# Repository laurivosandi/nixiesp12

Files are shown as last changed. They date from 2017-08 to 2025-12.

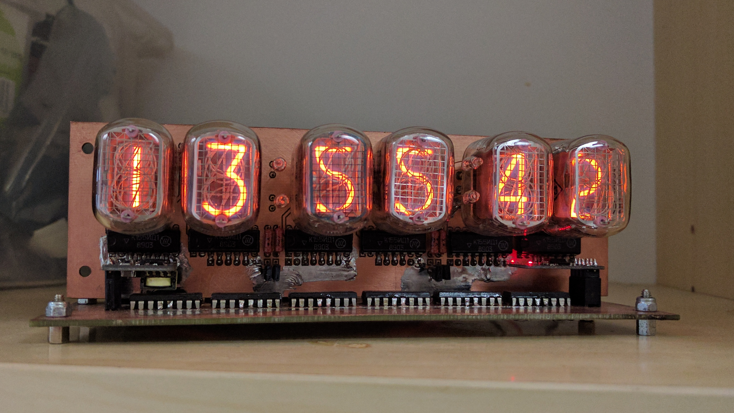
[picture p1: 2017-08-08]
photo.jpg

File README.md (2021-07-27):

# NixiESP12

## Intro

Yet another Nixie clock project!

Some highlights:

* K155ID1 driven IN-12A or IN-12B tubes for hour, minute, seconds. Use 36k resistors on these tubes.
* BS108 driven IN-6 or [similar 4*10mm neon bulbs](https://www.aliexpress.com/item/32344955038.html?spm=a2g0s.9042311.0.0.6ab14c4dCxpPZ0) for digit separation. Use 270k resistors on these bulbs.
* 74HC595 for serial to parallel conversion
* ESP8266 for time synchronization. Use 1k resistors for pull-up.
* LM1117-3.3V and LM1117-5V regulators for logic power supply
* No tube step up converter on-board, pin headers for connecting
  <a href="http://www.ebay.com/itm/DC-5V-12V-to-170V-DC-High-Voltage-NIXIE-Power-Supply-Module-PSU-NIXIE-TUBE-ERA-/322511957768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">third party power supply</a>
* KiCad design with 3D models from http://miniwatt.info

Some KiCad screenshots:



## Install

Install dependencies on an Ubuntu 18.04 box:

```bash
apt install -y python3-pip wget picocom make
pip3 install adafruit-ampy esptool
```

Boot ESP8266 with program pin held low and flash MicroPython:

```bash
cd firmware
make erase
make flash
```

Reboot ESP8266, open serial to to the controller and format filesystem:

```
import os
os.umount('/')
os.VfsLfs2.mkfs(bdev)
os.mount(bdev, '/')
```

Finish with by uploading scripts:

```bash
make upload
```

Power cycle the device and via WiFi connect to the device,
network name is MicroPython-XXXXXX and password is micropythoN.
Navigate to http://192.168.4.1 to start the configuration wizard.

## Configuring

If firmware is unable to connect to preconfigured wireless network
or it is started up for the first time wireless network
with password `micropythoN` is created.

Connect to that wireless network and open http://192.168.4.1
in web browser to configure the clock.

## Assembly tips

Some cheap 1117V regulators don't offer short circuit protection
and once blown pass through input voltage,
make sure you get ones with protection otherwise you can fry ESP8266
or serial-to-parallel chips.

Once the PCB is milled or etched make sure you clean the 180V rails thoroughly,
that voltage is high enough to cross gaps of 0.1mm.
Once that happens it burns a thick dark trace into the fiberglass of PCB and
it's pretty tricky to clean up.
The PCB is designed with 0.4mm clearance to be compliant with HV designs.
This clearance of course assumes that PCB traces are covered.
Either use solder mask or conformal coating.

Use the bench power supply to gradually power up the device,
at 9V set current limiter to 0.5A max.
5V linear regulator can be omitted and bypassed if 5V wall adapter is always used.
Otherwise 6V-12V wall adapters are suitable,
Thincan DBE60 9V wall adapters are pretty much perfect for the job.
Note that the higher the input voltage the more power is dissipated
as heat on the 3.3V and 5V voltage regulators, thus at 12V the device gets really hot.

## Debugging

* If you get nonsense reading during boot up sequence 0..9 likely the connection between serial-to-parallel chips and high voltage drivers
  is flaky. Either there are shorted pins or there is no connection at all. Check soldering joints and check for shorts between lines and line to ground.
* If single tube doesn't light up likely the gas has escaped the tube, find replacement tube.
* If single digit does not light up likely the tube socket pin is mangled or it is not properly soldered on the side where the PCB trace runs.

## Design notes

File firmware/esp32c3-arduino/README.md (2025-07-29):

# Arduino variant for ESP32C3

This firmware is designed to run on the [LilyGO T-01C3](https://lilygo.cc/products/t-01c3?srsltid=AfmBOopddAvO0gTIFNYZyTcoF1PxQjxZ0YAxuhoQviz9i5j4B0WOdg4l) board and serves as a drop-in replacement for the original ESP8266-based Nixie clock firmware.

**Compared to the ESP8266, the ESP32C3 provides much better clock accuracy and reliability, thanks to its advanced hardware and improved timekeeping features.**
If you received a Nixie clock from me, you are eligible for a free hardware upgrade - just contact me!

This firmware features a high refresh rate display with advanced dimming and blending effects, leveraging the ESP32's RMT (Remote Control) peripheral for precise timing and smooth transitions.

## Highlights

- **High Refresh Rate:** Achieves smooth digit transitions and flicker-free display using RMT hardware
- **Dimming & Blending:** Configurable dimming and blending for night mode and digit transitions
- **WiFiManager Configuration:** Easily configure all clock options via a web portal
- **Prometheus Metrics:** Exposes runtime and system metrics for monitoring

## Configuration Options via WiFiManager

- **NTP Time Server:** Set the network time server for clock synchronization
- **City:** Select your city for timezone presets
- **Timezone:** Manually specify the POSIX timezone string
- **Display Mode:** Choose between time, date, or alternating time/date display
- **Dimming Duty Cycle:** Adjust brightness for night mode
- **Dimming Start/End:** Set hours for automatic dimming
- **Blending Duration:** Control the duration of digit blending transitions
- **Hour Format:** Select 12-hour or 24-hour display

## Prometheus Metrics

The firmware exposes the following metrics for monitoring:

- `nixie_boot_timestamp_seconds`: Boot time of the device
- `nixie_last_ntp_sync_timestamp_seconds`: Last successful NTP synchronization
- `nixie_littlefs_total_bytes`: Total LittleFS storage size
- `nixie_littlefs_used_bytes`: Used LittleFS storage
- `nixie_uptime_seconds`: Device uptime
- `nixie_display_task_iterations_total`: Number of display task iterations
- `nixie_ntp_sync_count_total`: Number of NTP sync events
- `nixie_wifi_manager_process_count_total`: Number of WiFiManager process events

## Advanced Features

- **Automatic NTP Sync:** Periodically synchronizes time with the configured NTP server
- **Stale NTP Detection:** Blinks all digits and colons if NTP sync is stale
- **Critical Section Display Updates:** Uses FreeRTOS and portMUX for safe, high-speed display updates

## Getting Started

1. Flash the firmware to your ESP32-C3
2. Connect to the WiFiManager AP (SSID is based on device MAC)
3. Configure your clock settings via the web portal
4. Monitor metrics via Prometheus-compatible tools

---

For more details, see the source code and comments.

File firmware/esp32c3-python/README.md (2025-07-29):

# MicroPython variant for ESP32C3

This firmware is designed to run on ESP32-C3 boards using MicroPython. It drives a Nixie tube clock with high refresh rate, advanced dimming, and blending effects, leveraging the ESP32's RMT peripheral for precise timing

## Highlights

- **High Refresh Rate:** Smooth, flicker-free display using RMT hardware
- **Dimming & Blending:** Configurable night mode brightness and digit blending transitions
- **Configurable via `config.py`:** All major settings can be overridden by uploading a `config.py` file
- **NTP Synchronization:** Periodically syncs time with NTP servers
- **Timezone & DST Support:** Adjustable timezone and daylight saving settings

## Configuration Options

You can override any of these defaults by uploading a `config.py` file:

- `CONFIG_TIMEZONE`: Timezone offset from UTC (default: 2)
- `CONFIG_DAYLIGHT_SAVING_ENABLED`: Enable/disable DST (default: True)
- `CONFIG_NTP_SYNC_INTERVAL_HOURS`: NTP sync interval (default: 24)
- `CONFIG_DIMMING_ENABLED`: Enable night dimming (default: True)
- `CONFIG_DIMMING_BRIGHTNESS`: Night brightness (default: 0.4)
- `CONFIG_DIMMING_START`: Dimming start hour (default: 15)
- `CONFIG_DIMMING_END`: Dimming end hour (default: 6)
- `CONFIG_DIMMING_GAMMA`: Dimming gamma correction (default: 2.2)
- `CONFIG_BLENDING_ENABLED`: Enable digit blending (default: True)
- `CONFIG_BLENDING_DURATION`: Blending duration in ms (default: 150)
- `CONFIG_NETWORKS`: Dictionary of SSIDs and passwords for auto-connect

## Features

- **WiFi Auto-Connect:** Scans and connects to known networks
- **NTP Time Sync:** Sets system time via NTP after WiFi connection
- **Display Modes:** Time, date, and temperature rendering functions
- **RMT-Based Display:** Uses ESP32 RMT for precise display timing
- **Night Mode:** Automatic dimming based on configured hours
- **Blending:** Smooth digit transitions for improved aesthetics

## Usage

1. Flash MicroPython to your ESP32-C3 board
2. Upload `main.py` and (optionally) `config.py` to the device
3. Reboot the board. The clock will auto-connect to WiFi, sync time, and start displaying

## Notes

- The firmware is intended for advanced users familiar with MicroPython and ESP32 hardware
- For custom settings, create and upload a `config.py` file with your overrides
- RMT and SPI pin assignments are set for typical Nixie clock hardware; adjust as needed for your build

---

For more details, see the source code and

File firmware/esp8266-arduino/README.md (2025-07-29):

# Arduino variant for ESP8266

This firmware is designed for Nixie tube clocks using the ESP8266 microcontroller.

## Features

- WiFi configuration via captive portal (WiFiManager)
- NTP time synchronization
- Time and date display
- Timezone and NTP server configuration
- Clock drift mitigation using the ezTime library

## Note

The main issue with ESP8266-based clocks is clock drift. This firmware uses the ezTime library to reduce drift, but accuracy is still limited compared to ESP32-based

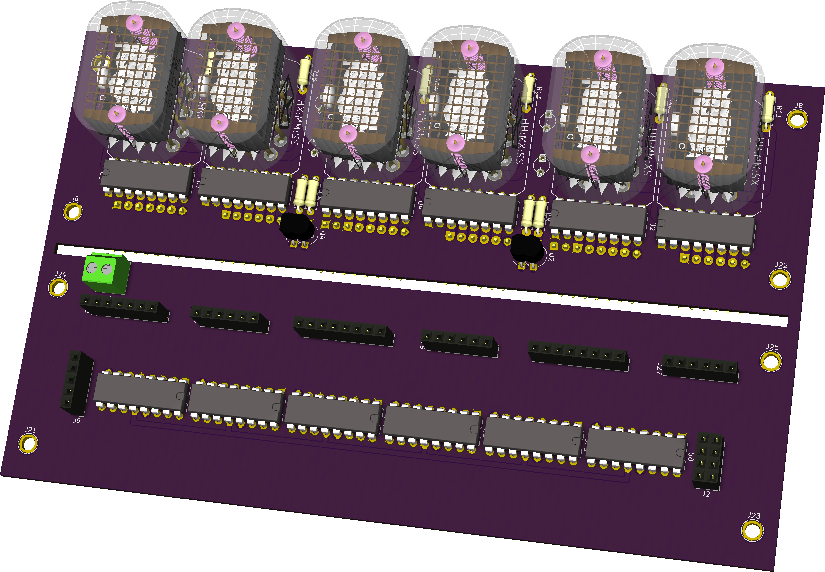
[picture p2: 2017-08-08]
nixiesp.png

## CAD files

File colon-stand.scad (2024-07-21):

H = 21;
Q = 1.2;
D = 1;
module j() {
    cylinder(h=100, d=D, $fn=20);
    translate([0,0,H-Q]) cylinder(5,0,5,$fn=20);
    cylinder(Q,Q,0,$fn=20);
}

difference() {
  hull() {
    translate([6.5, 0]) cylinder(h=H, d=4, $fn=50);
    translate([-6.5, 0]) cylinder(h=H, d=4, $fn=50);
  }
  translate([6.5, 0]) j();
  translate([-6.5, 0]) j();
  translate([3.5, 0]) j();
  translate([-3.5, 0]) j();

}

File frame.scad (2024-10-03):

PCB_THICKNESS = 1.7;
EDGE_LENGTH = 54;
WRAPAROUND = 2;

module thingie() {
  translate([1, 0, 0]) {
    difference() {
      cube([
        EDGE_LENGTH + 2 * WRAPAROUND,
        EDGE_LENGTH + 2 * WRAPAROUND*2 + PCB_THICKNESS,
        9]);
      translate([EDGE_LENGTH+17+5+3, EDGE_LENGTH+5+5]) {
        cylinder(10, EDGE_LENGTH+5, EDGE_LENGTH+5, $fn=500);
      };

      translate([-141,73]) {
        cylinder(10, 155, 155, $fn=500);
      };


      translate([WRAPAROUND, WRAPAROUND*3,1])  {
        translate([14, PCB_THICKNESS,0])  {
          cube([PCB_THICKNESS,EDGE_LENGTH,20]);
        }
        cube([EDGE_LENGTH,PCB_THICKNESS,20]);
      }
    }
  }
}

thingie();
mirror([1,0,0]) {
  thingie();
}

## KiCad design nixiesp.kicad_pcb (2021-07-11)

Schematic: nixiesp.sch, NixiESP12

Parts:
C1, C3: C; C_Disc_D4.3mm_W1.9mm_P5.00mm
C2, C4: CP; CP_Radial_D8.0mm_P3.50mm
J1: Power 9-15V; TerminalBlock_Pheonix_PT-3.5mm_2pol
J2: ESP8266; Socket_Strip_Straight_2x04_Pitch2.54mm
J3, J10, J12: CONN_01X06; Pin_Header_Angled_1x06_Pitch2.54mm
J4, J6, J13: CONN_01X07; Pin_Header_Angled_1x07_Pitch2.54mm
J5, J27, J29: CONN_01X06; Socket_Strip_Straight_1x06_Pitch2.54mm
J9: CONN_01X05; Socket_Strip_Straight_1x05_Pitch2.54mm
J11, J14, J31: CONN_01X07; Socket_Strip_Straight_1x07_Pitch2.54mm
J15, J16, J17, J18, J19, J20, J21, J23, J24, J25: CONN_01X01; 1pin
N1: HX:MM:SS; russian-nixies-IN-12
N2: XH:MM:SS; russian-nixies-IN-12
N3: HH:MX:SS; russian-nixies-IN-12
N4: HH:XM:SS; russian-nixies-IN-12
N5: HH:MM:SX; russian-nixies-IN-12
N6: HH:MM:XS; russian-nixies-IN-12
N7, N8, N9, N10: IN-6; russian-nixies-IN-6
Q1, Q2, Q3, Q4: BS107; TO-92_Inline_Wide
R1, R2: 2.2k; R_Axial_DIN0207_L6.3mm_D2.5mm_P7.62mm_Horizontal
R7, R8, R9, R10: 15k; R_Axial_DIN0207_L6.3mm_D2.5mm_P7.62mm_Horizontal
R11, R12, R13, R14, R15, R16: 10k; R_Axial_DIN0207_L6.3mm_D2.5mm_P7.62mm_Horizontal
U1, U5, U8, U11, U13, U14: 74HC595; DIP-16_W7.62mm
U2, U3, U4, U6, U7, U9: K155ID1; DIP-16_W7.62mm
U10: LM1117-5.0; SOT-223
U12: LM1117-3.3; SOT-223

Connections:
/data: J2.3, R2.2, U8.14 (SER)
/latch: J2.5, R1.1, U1.12 (RCLK), U5.12 (RCLK), U8.12 (RCLK), U11.12 (RCLK), U13.12 (RCLK), U14.12 (RCLK)
unnamed: J1.2, J9.1, U10.3 (VI), U12.3 (VI)
unnamed: J3.2, U2.7
unnamed: J3.3, U2.6
unnamed: J3.5, U2.4
unnamed: J3.6, U2.3
unnamed: J4.2, U3.7
unnamed: J4.3, U3.6
unnamed: J4.5, U3.4
unnamed: J4.6, U3.3
unnamed: J4.7, Q1.2 (G)
unnamed: J5.1, U1.2 (QC)
unnamed: J5.2, U1.3 (QD)
unnamed: J5.3, U1.4 (QE)
unnamed: J5.5, U1.5 (QF)
unnamed: J5.6, U1.6 (QG)
unnamed: J6.2, U6.7
unnamed: J6.3, U6.6
unnamed: J6.5, U6.4
unnamed: J6.6, U6.3
unnamed: J6.7, Q3.2 (G)
unnamed: J10.1, Q2.2 (G)
unnamed: J10.2, U4.7
unnamed: J10.3, U4.6
unnamed: J10.5, U4.4
unnamed: J10.6, U4.3
unnamed: J11.2, U11.3 (QD)
unnamed: J11.3, U11.4 (QE)
unnamed: J11.5, U11.5 (QF)
unnamed: J11.6, U11.6 (QG)
unnamed: J11.7, U1.1 (QB)
unnamed: J12.1, Q4.2 (G)
unnamed: J12.2, U7.7
unnamed: J12.3, U7.6
unnamed: J12.5, U7.4
unnamed: J12.6, U7.3
unnamed: J13.2, U9.7
unnamed: J13.3, U9.6
unnamed: J13.5, U9.4
unnamed: J13.6, U9.3
unnamed: J13.7, R7.1, R8.1, R9.1, R10.1, R11.1, R12.1, R13.1, R14.1, R15.1, R16.1
unnamed: J14.2, U13.3 (QD)
unnamed: J14.3, U13.4 (QE)
unnamed: J14.5, U13.5 (QF)
unnamed: J14.6, U13.6 (QG)
unnamed: J14.7, U5.1 (QB)
unnamed: J27.2, U8.3 (QD)
unnamed: J27.3, U8.4 (QE)
unnamed: J27.5, U8.5 (QF)
unnamed: J27.6, U8.6 (QG)
unnamed: J29.1, U5.2 (QC)
unnamed: J29.2, U5.3 (QD)
unnamed: J29.3, U5.4 (QE)
unnamed: J29.5, U5.5 (QF)
unnamed: J29.6, U5.6 (QG)
unnamed: J31.2, U14.3 (QD)
unnamed: J31.3, U14.4 (QE)
unnamed: J31.5, U14.5 (QF)
unnamed: J31.6, U14.6 (QG)
unnamed: J9.5, J31.7
unnamed: N1.0, U7.10
unnamed: N1.1, U7.14
unnamed: N1.2, U7.2
unnamed: N1.3, U7.15
unnamed: N1.4, U7.16
unnamed: N1.5, U7.1
unnamed: N1.6, U7.13
unnamed: N1.7, U7.11
unnamed: N1.8, U7.8
unnamed: N1.9, U7.9
unnamed: N1.A, R15.2
unnamed: N2.0, U9.10
unnamed: N2.1, U9.14
unnamed: N2.2, U9.2
unnamed: N2.3, U9.15
unnamed: N2.4, U9.16
unnamed: N2.5, U9.1
unnamed: N2.6, U9.13
unnamed: N2.7, U9.11
unnamed: N2.8, U9.8
unnamed: N2.9, U9.9
unnamed: N2.A, R16.2
unnamed: N3.0, U4.10
unnamed: N3.1, U4.14
unnamed: N3.2, U4.2
unnamed: N3.3, U4.15
unnamed: N3.4, U4.16
unnamed: N3.5, U4.1
unnamed: N3.6, U4.13
unnamed: N3.7, U4.11
unnamed: N3.8, U4.8
unnamed: N3.9, U4.9
unnamed: N3.A, R13.2
unnamed: N4.0, U6.10
unnamed: N4.1, U6.14
unnamed: N4.2, U6.2
unnamed: N4.3, U6.15
unnamed: N4.4, U6.16
unnamed: N4.5, U6.1
unnamed: N4.6, U6.13
unnamed: N4.7, U6.11
unnamed: N4.8, U6.8
unnamed: N4.9, U6.9
unnamed: N4.A, R14.2
unnamed: N5.0, U2.10
unnamed: N5.1, U2.14
unnamed: N5.2, U2.2
unnamed: N5.3, U2.15
unnamed: N5.4, U2.16
unnamed: N5.5, U2.1
unnamed: N5.6, U2.13
unnamed: N5.7, U2.11
unnamed: N5.8, U2.8
unnamed: N5.9, U2.9
unnamed: N5.A, R11.2
unnamed: N6.0, U3.10
unnamed: N6.1, U3.14
unnamed: N6.2, U3.2
unnamed: N6.3, U3.15
unnamed: N6.4, U3.16
unnamed: N6.5, U3.1
unnamed: N6.6, U3.13
unnamed: N6.7, U3.11
unnamed: N6.8, U3.8
unnamed: N6.9, U3.9
unnamed: N6.A, R12.2
unnamed: N7.A, R10.2
unnamed: N7.K, Q4.1 (D)
unnamed: N8.A, R7.2
unnamed: N8.K, Q1.1 (D)
unnamed: N9.A, R8.2
unnamed: N9.K, Q2.1 (D)
unnamed: N10.A, R9.2
unnamed: N10.K, Q3.1 (D)
unnamed: U1.9 (~QH), U14.14 (SER)
unnamed: U1.14 (SER), U11.9 (~QH)
unnamed: U5.9 (~QH), U11.14 (SER)
unnamed: U5.14 (SER), U13.9 (~QH)
unnamed: U8.9 (~QH), U13.14 (SER)

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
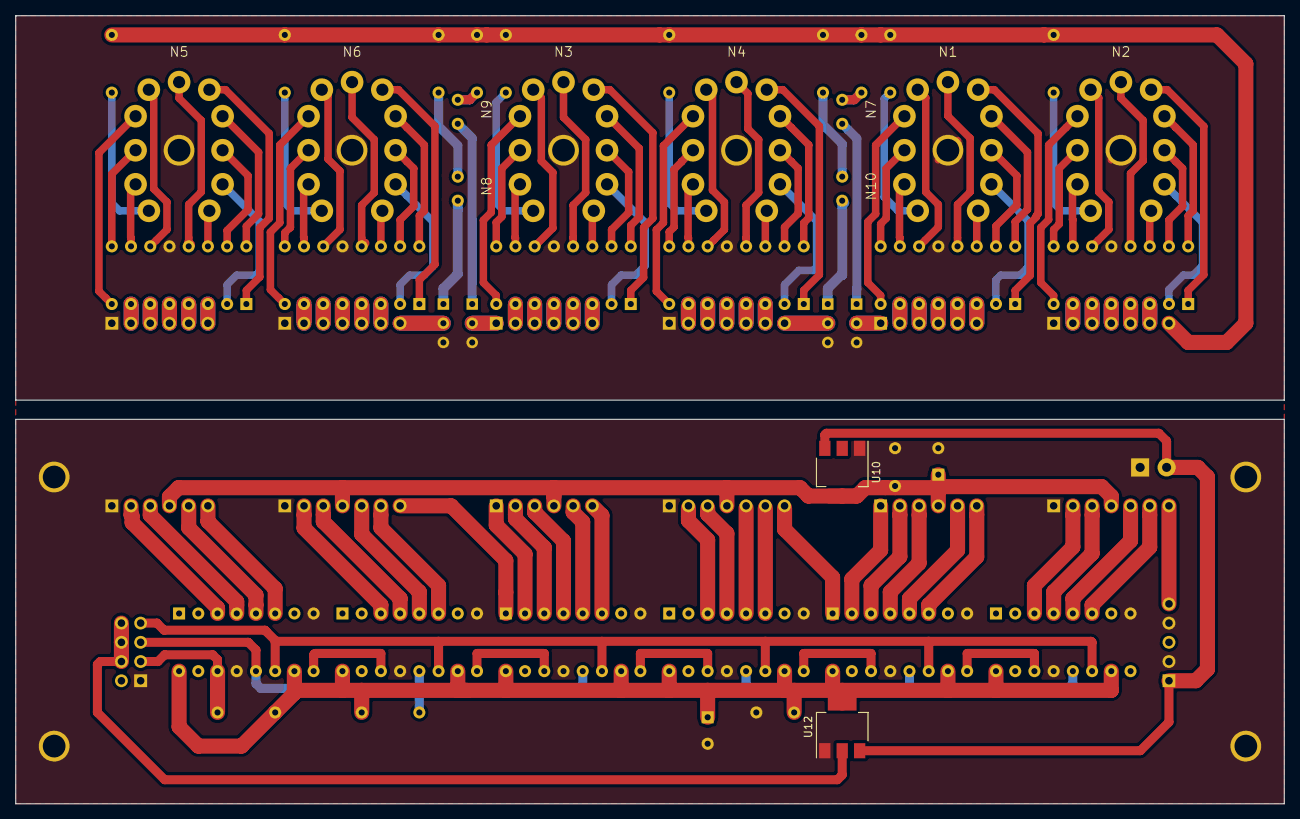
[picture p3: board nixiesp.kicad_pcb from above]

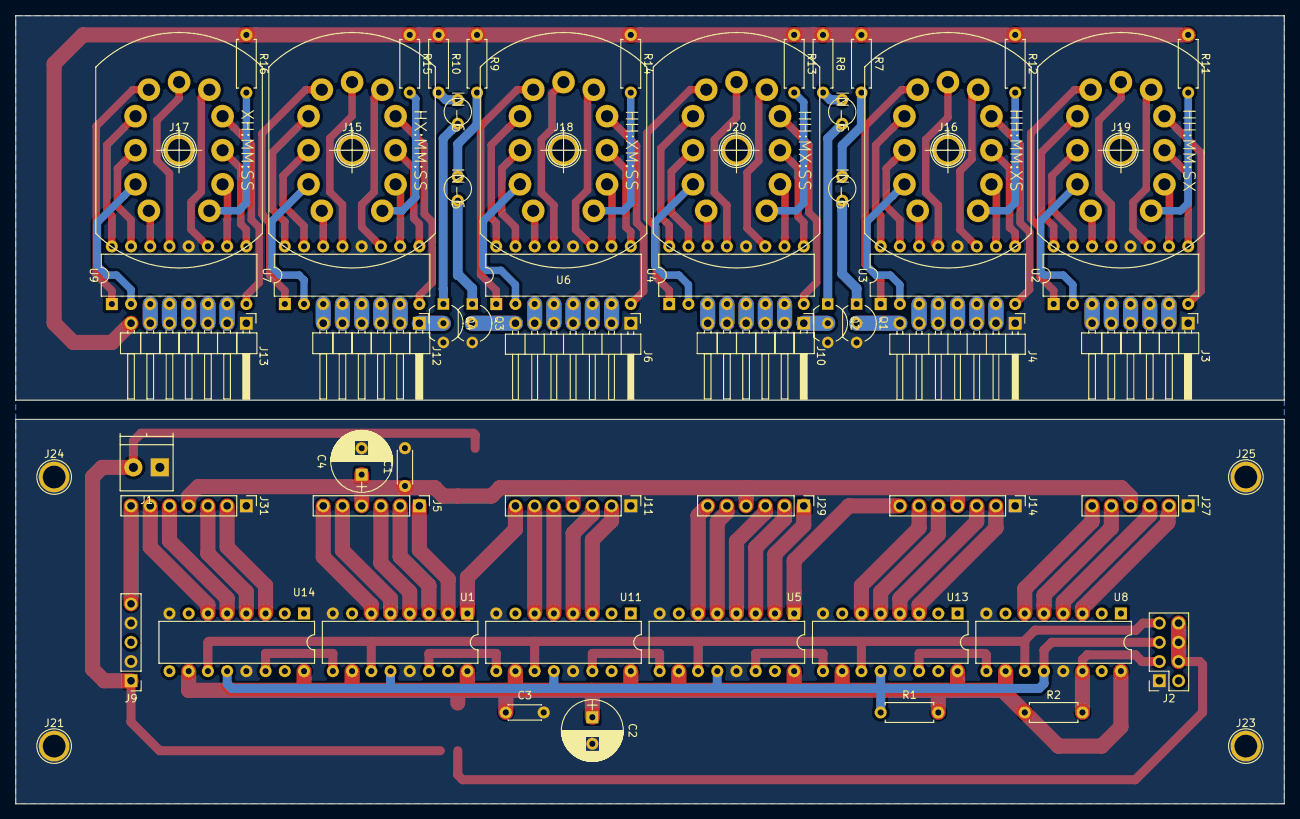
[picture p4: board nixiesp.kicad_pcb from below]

Board: 2 copper layers, 167.6 x 104.1 mm, 69 parts (67 on the bottom side), 143 nets.

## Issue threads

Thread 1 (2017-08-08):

Pull up resistors missing

laurivosandi, 2017-08-08:
Some of the ESP pins need pull up resistor to prevent booting into flashing mode

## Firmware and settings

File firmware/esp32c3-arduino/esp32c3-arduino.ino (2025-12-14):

#include <Arduino.h>
#include <WiFiManager.h>
#include <WiFi.h>
#include "esp_sntp.h"
#include <time.h>
#include <math.h>
#include <driver/rmt.h>
#include "cities.h"
#include <LittleFS.h>

// --- Configuration ---
#define CONFIG_CPU_FREQUENCY 80000000
#define CONFIG_RMT_DIVISOR 50
#define CONFIG_REFRESH_RATE 50
#define REFRESH_CYCLE CONFIG_CPU_FREQUENCY / CONFIG_RMT_DIVISOR / CONFIG_REFRESH_RATE - 100

static_assert(REFRESH_CYCLE > 0, "REFRESH_CYCLE must be > 0");
static_assert(REFRESH_CYCLE < 32768, "REFRESH_CYCLE must be < 32768");


// --- Pin Definitions ---
#define PIN_CLOCK 20
#define PIN_LATCH 9
#define PIN_DATA 2
#define PIN_UNUSED 11

// --- Colon and Symbol Definitions ---
#define COLON_LEFT_BOTTOM (1ULL << (17 + 16))
#define COLON_LEFT_TOP (1ULL << (18 + 16))
#define COLON_RIGHT_BOTTOM (1ULL << 17)
#define COLON_RIGHT_TOP (1ULL << 18)

#define COLON_LEFT_BOTH (COLON_LEFT_TOP | COLON_LEFT_BOTTOM)
#define COLON_RIGHT_BOTH (COLON_RIGHT_TOP | COLON_RIGHT_BOTTOM)
#define COLON_BOTTOM_BOTH (COLON_LEFT_BOTTOM | COLON_RIGHT_BOTTOM)
#define COLON_TOP_BOTH (COLON_LEFT_TOP | COLON_RIGHT_TOP)
#define COLON_ALL (COLON_LEFT_BOTH | COLON_RIGHT_BOTH)

#define IN15A_MICRO 0
#define IN15A_PERCENT 2
#define IN15A_PETA 3
#define IN15A_KILO 4
#define IN15A_MEGA 5
#define IN15A_MILLI 6
#define IN15A_PLUS 7
#define IN15A_MINUS 8
#define IN15A_PICO 9


#define NTP_SYNC_TIMEOUT_SECONDS 8*3600

int configDimmingDutyCycle = 0;
int configDimmingStart = 0;
int configDimmingEnd = 0;
int configHourFormat = 12;

int current_dimming_duty_cycle;
enum typeOperationMode {
  OPERATION_MODE_NORMAL,
  OPERATION_MODE_DIMMED,
} operationModeCurrent = OPERATION_MODE_NORMAL;

#define DISPLAY_MODE_TIME 1
#define DISPLAY_MODE_DATE 2
#define DISPLAY_MODE_DATETIME 3

int configDisplayModesEnabled = 1;
int displayModeCurrent = 1;

WiFiManager wm;

const char displayModesCombobox[] = R"(
<br/>
<label for="displayModeCombobox">Clock display format</label>
<select name="timeDisplay" id="displayModeCombobox" onchange="document.getElementById('displayMode').value = this.value">
  <option value="1">Time</option>
  <option value="2">Date</option>
  <option value="3">Time and Date</option>
</select>
<script>
  document.getElementById("displayModeCombobox").value = document.getElementById("displayMode").value;
  document.querySelector("[for='displayMode']").hidden = true;
  document.getElementById("displayMode").hidden = true;
</script>)";


WiFiManagerParameter paramNetworkTimeServer("networkTimeServer", "Network time server", "ee.pool.ntp.org", 63);
WiFiManagerParameter paramDisplayMode("displayMode", "Will be hidden", "1", 2);
WiFiManagerParameter paramDisplayModeCombobox(displayModesCombobox);
WiFiManagerParameter paramCity(cities);
WiFiManagerParameter paramTimezone("timezone", "Timezone encoding", "EET-2EEST,M3.5.0/3,M10.5.0/4", 30);
#define CONFIG_TIMEZONE "EET-2EEST,M3.5.0/3,M10.5.0/4" // Estonia, adjust as needed

const char dimmerSliderSnippet[] = R"(
<br/><label for='dimming_duty_cycle_slider'>Night time dimming duty cycle (%)</label>
<input type="range" min="500" max="32767" value="1000" class="slider" id="dimming_duty_cycle_slider" onchange="document.getElementById('dimming_duty_cycle').value = this.value">
<script>
document.getElementById('dimming_duty_cycle').hidden = true;
</script>
)";
WiFiManagerParameter paramDimmingDutyCycle("dimming_duty_cycle", "", "1000", 6);
WiFiManagerParameter paramDimmingDutyCycleSlider(dimmerSliderSnippet);

time_t bootTimestamp = 0;
time_t lastNtpSyncTimestamp = 0;


// Dimmer settings
volatile long displayInterruptCount = 0;

const char blendingSliderSnippet[] = R"(
<br/><label for='blending_duration_slider'>Blending duration (0 .. 400ms)</label>
<input type='range' min='0' max='400' value='200' class='slider' id='blending_duration_slider' onchange="document.getElementById('blending_duration').value = this.value">
<script>
document.getElementById('blending_duration').hidden = true;
</script>
)";
WiFiManagerParameter paramBlendingDuration("blending_duration", "", "200", 4);
WiFiManagerParameter paramBlendingDurationSlider(blendingSliderSnippet);


const char dimmingStartCombobox[] = R"(
<br/>
<label for='dimming_start_hour'>Night time dimming start time</label>
<select name='dimming_start' id='dimming_start_hour' onchange="document.getElementById('dimming_start').value = this.value">
  <option value='13'>13:00</option>
  <option value='14'>14:00</option>
  <option value='15'>15:00</option>
  <option value='16'>16:00</option>
  <option value='17'>17:00</option>
  <option value='18'>18:00</option>
  <option value='19'>19:00</option>
  <option value='20'>20:00</option>
  <option value='21'>21:00</option>
  <option value='22'>22:00</option>
  <option value='23'>23:00</option>
</select>
<script>
document.getElementById('dimming_start_hour').value = "22";
document.getElementById('dimming_start').hidden = true;
</script>
)";

const char dimmingEndCombobox[] = R"(
<br/>
<label for='dimming_end_hour'>Night time dimming end time</label>
<select name='dimming_end' id='dimming_end_hour' onchange="document.getElementById('dimming_end').value = this.value">
  <option value='4'>4:00</option>
  <option value='5'>5:00</option>
  <option value='6'>6:00</option>
  <option value='7'>7:00</option>
  <option value='8'>8:00</option>
  <option value='9'>9:00</option>
  <option value='10'>10:00</option>
  <option value='11'>11:00</option>
  <option value='12'>12:00</option>
</select>
<script>
document.getElementById('dimming_end_hour').value = "6";
document.getElementById('dimming_end').hidden = true;
</script>
)";

const char hourFormatCombobox[] = R"(
<br/>
<label for="hourFormatCombobox">Hour format</label>
<select name="hour_format" id="hourFormatCombobox" onchange="document.getElementById('hour_format').value = this.value">
  <option value="24">24-hour</option>
  <option value="12">12-hour</option>
</select>
<script>
  document.getElementById("hourFormatCombobox").value = "12";
  document.getElementById("hour_format").hidden = true;
</script>
)";

WiFiManagerParameter paramHourFormat("hour_format", "", "12", 3);
WiFiManagerParameter paramHourFormatCombobox(hourFormatCombobox);
WiFiManagerParameter paramDimmingStart("dimming_start", "", "22", 3);
WiFiManagerParameter paramDimmingStartCombobox(dimmingStartCombobox);
WiFiManagerParameter paramDimmingEnd("dimming_end", "", "6", 3);
WiFiManagerParameter paramDimmingEndCombobox(dimmingEndCombobox);

// --- NTP Sync Counter ---
volatile unsigned long displayTaskIterationsCount = 0;
volatile unsigned long configBlendingDuration = 0;
volatile unsigned long ntpSyncCount = 0;
volatile unsigned long wifiManagerProcessCount = 0;

void IRAM_ATTR timeavailable(struct timeval *t) {
    ntpSyncCount++;
    if (bootTimestamp == 0 && t) {
        bootTimestamp = t->tv_sec;
    }
    if (t) {
        lastNtpSyncTimestamp = t->tv_sec;
    }
}

#define RMT_TX_GPIO 9


// --- State ---
uint64_t STATE_PREVIOUS = 0x787878787878ULL;
int STATE_REFRESH_MODE = 0;

// --- Helper Functions ---
void spi_write_bytes(const uint8_t* data, size_t len) {
    for (size_t i = 0; i < len; i++) {
        uint8_t b = data[i];
        for (int bit = 7; bit >= 0; bit--) {
            digitalWrite(PIN_CLOCK, LOW);
            digitalWrite(PIN_DATA, (b >> bit) & 1);
            digitalWrite(PIN_CLOCK, HIGH);
        }
    }
}

int clamp(int v, int lower = -99, int upper = 99) {
    if (v > upper) return upper;
    if (v < lower) return lower;
    return v;
}

uint64_t render_digit(int j, int position = 0) {
    static const int table[11] = {11, 9, 12, 8, 0, 4, 1, 3, 2, 10, 15};
    if (j < -1 || j > 9) j = 10;
    if (j == -1) j = 10;
    return ((uint64_t)table[j] << 3) << (position * 8);
}

uint64_t render_digits(int d5, int d4, int d3, int d2, int d1, int d0) {
    uint64_t z = 0;
    int vals[6] = {d0, d1, d2, d3, d4, d5};
    for (int position = 0; position < 6; position++) {
        z |= render_digit(vals[position], position);
    }
    return z;
}

uint64_t render_time(bool colons = true) {
    struct tm timeinfo;
    time_t now = time(nullptr);
    localtime_r(&now, &timeinfo);
    int h = timeinfo.tm_hour % configHourFormat;
    if (configHourFormat == 12 && h == 0) {
        h = 12; // TODO: Parameter to configure 12-hour format
    }
    int m = timeinfo.tm_min;
    int s = timeinfo.tm_sec;
    return render_digits(h / 10, h % 10, m / 10, m % 10, s / 10, s % 10) | (colons ? COLON_ALL : 0);
}

uint64_t render_date(bool colons = true) {
    struct tm timeinfo;
    time_t now = time(nullptr);
    localtime_r(&now, &timeinfo);
    int y = timeinfo.tm_year % 100;
    int m = timeinfo.tm_mon + 1;
    int d = timeinfo.tm_mday;
    return render_digits(y / 10, y % 10, m / 10, m % 10, d / 10, d % 10) | (colons ? COLON_BOTTOM_BOTH : 0);
}

uint64_t render_temperature(int t) {
    int val = abs(clamp(t));
    return render_digits(-1, t < 0 ? IN15A_MINUS : -1, val / 10, val % 10, -1, -1) | COLON_RIGHT_TOP;
}

void rmt_pulse(uint32_t duration) {
    rmt_data_t items[3];
    items[0].level0 = 1; items[0].duration0 = 1; // latch immediately
    items[0].level1 = 0; items[0].duration1 = duration;
    items[1].level0 = 1; items[1].duration0 = 1;
    items[1].level1 = 0; items[1].duration1 = 1;
    rmtWriteAsync(RMT_TX_GPIO, items, duration == 0 ? 1 : 2);
}

void display_static(uint64_t value) {
    uint8_t bytes[6];
    for (int i = 0; i < 6; i++) bytes[i] = (value >> (8 * (5 - i))) & 0xFF;
    spi_write_bytes(bytes, 6);
    rmt_data_t items[1];
    items[0].level0 = 1; items[0].duration0 = 1;
    items[0].level1 = 0; items[0].duration1 = 1;
    rmtWrite(RMT_TX_GPIO, items, 1, RMT_WAIT_FOR_EVER);
}

void display_dimmed(uint64_t value, int duty) {
    uint8_t bytes[6];
    for (int i = 0; i < 6; i++) bytes[i] = (value >> (8 * (5 - i))) & 0xFF;
    if (duty >= 32767) {
        display_static(value);
    } else {
        spi_write_bytes(bytes, 6);
        rmt_pulse(duty);
        uint8_t blank[6] = {0x78, 0x78, 0x78, 0x78, 0x78, 0x78};
        spi_write_bytes(blank, 6);
    }
}

void display_blended(uint64_t value, uint64_t prev, float progression) {
    int duty = 32767 * progression;
    if (duty < 500) { duty = 500; }
    uint8_t bytes[6], prev_bytes[6];
    for (int i = 0; i < 6; i++) {
        bytes[i] = (value >> (8 * (5 - i))) & 0xFF;
        prev_bytes[i] = (prev >> (8 * (5 - i))) & 0xFF;
    }
    if (progression >= 1.0) {
        display_static(value);
    } else {
        spi_write_bytes(bytes, 6);
        rmt_pulse(duty);
        spi_write_bytes(prev_bytes, 6);
    }
}

bool isNtpStale() {
    time_t now = time(nullptr);
    return (lastNtpSyncTimestamp == 0) || (now - lastNtpSyncTimestamp > NTP_SYNC_TIMEOUT_SECONDS);
}

void handleMetrics(){
    String buf = "";


    buf += "nixie_sketch_size_bytes ";
    buf += ESP.getSketchSize();
    buf += "\n";

    buf += "nixie_flash_space_bytes ";
    buf += ESP.getFlashChipSize();
    buf += "\n";

    buf += "nixie_free_heap_bytes ";
    buf += ESP.getFreeHeap();
    buf += "\n";

    buf += "nixie_min_free_heap_bytes ";
    buf += ESP.getMinFreeHeap();
    buf += "\n";

    buf += "nixie_cpu_frequency_mhz ";
    buf += getCpuFrequencyMhz();
    buf += "\n";

    buf += "nixie_task_count ";
    buf += uxTaskGetNumberOfTasks();
    buf += "\n";

    buf += "nixie_wifi_rssi_dbm ";
    buf += WiFi.RSSI();
    buf += "\n";

    buf += "nixie_wifi_channel ";
    buf += WiFi.channel();
    buf += "\n";

    int wifiStatus = WiFi.status();
    const char* wifiStatusStr = "UNKNOWN";
    switch (wifiStatus) {
        case WL_IDLE_STATUS: wifiStatusStr = "IDLE"; break;
        case WL_NO_SSID_AVAIL: wifiStatusStr = "NO_SSID_AVAIL"; break;
        case WL_SCAN_COMPLETED: wifiStatusStr = "SCAN_COMPLETED"; break;
        case WL_CONNECTED: wifiStatusStr = "CONNECTED"; break;
        case WL_CONNECT_FAILED: wifiStatusStr = "CONNECT_FAILED"; break;
        case WL_CONNECTION_LOST: wifiStatusStr = "CONNECTION_LOST"; break;
        case WL_DISCONNECTED: wifiStatusStr = "DISCONNECTED"; break;
    }
    buf += "nixie_wifi_status_info{status=\"";
    buf += wifiStatusStr;
    buf += "\"} ";
    buf += wifiStatus;
    buf += "\n";

    buf += "nixie_wifi_info{ssid=\"";
    buf += WiFi.SSID();
    buf += "\",bssid=\"";
    buf += WiFi.BSSIDstr();
    buf += "\",ip=\"";
    buf += WiFi.localIP().toString();
    buf += "\",gateway=\"";
    buf += WiFi.gatewayIP().toString();
    buf += "\",dns=\"";
    buf += WiFi.dnsIP().toString();
    buf += "\"} 1\n";

    buf += "nixie_ntp_sync_count ";
    buf += ntpSyncCount;
    buf += "\n";

    buf += "nixie_wifi_manager_process_count ";
    buf += wifiManagerProcessCount;
    buf += "\n";

    buf += "nixie_task_stack_high_water_mark_bytes ";
    buf += uxTaskGetStackHighWaterMark(NULL);
    buf += "\n";

    buf += "nixie_display_task_iterations_count ";
    buf += displayTaskIterationsCount;
    buf += "\n";

    if (bootTimestamp > 0) {
        buf += "nixie_boot_timestamp_seconds ";
        buf += bootTimestamp;
        buf += "\n";
    }

    buf += "nixie_last_ntp_sync_timestamp_seconds ";
    buf += lastNtpSyncTimestamp;
    buf += "\n";

    buf += "nixie_littlefs_total_bytes ";
    buf += LittleFS.totalBytes();
    buf += "\n";

    buf += "nixie_littlefs_used_bytes ";
    buf += LittleFS.usedBytes();
    buf += "\n";

    wm.server->send(200, "text/plain", buf);
}

unsigned char timeserver[63] = {'\0'};
unsigned char timezone[30] = {'\0'};
bool ntp_started = false;

int loadClockConfig() {
  File file = LittleFS.open("/timezone", "r");
  if (!file) { return 1; }
  if (!file.read(timezone, sizeof(timezone))) { return 2; }

  file = LittleFS.open("/timeserver", "r");
  if (!file) { return 3; }
  if (!file.read(timeserver, sizeof(timeserver))) { return 4; }

  if (!ntp_started) {
    Serial.print("Using time server: ");
    Serial.println((const char*)timeserver);
    configTime(0, 0, (const char*)timeserver);
    ntp_started = true;
  } else {
    Serial.print("NTP already started, reset to apply new time server");

  }

  Serial.print("Using timezone: ");
  Serial.println((const char*)timezone);
  setenv("TZ", (const char*)timezone, 1);
  tzset();


  unsigned char modes[1] = {'\0'};
  file = LittleFS.open("/modes", "r");
  if (!file) { return 5; }
  if (!file.read(modes, sizeof(modes))) { return 6; }
  displayModeCurrent = atoi((const char*)modes);
  Serial.print("Enabled display modes:");
  if (displayModeCurrent & DISPLAY_MODE_DATE) {
    Serial.print(" DATE");
  }
  if (displayModeCurrent & DISPLAY_MODE_TIME) {
    Serial.print(" TIME");
  }
  Serial.println();

  unsigned char bufDimming[10] = {'\0'};
  file = LittleFS.open("/dimming", "r");
  if (!file) { return 7; }
  if (!file.read(bufDimming, sizeof(bufDimming))) { return 8; }
  configDimmingDutyCycle = atoi((const char*)bufDimming); // ensure integer
  Serial.print("Night time dimming duty cycle: ");
  Serial.println(configDimmingDutyCycle);

  unsigned char bufBlending[10] = {'\0'};
  file = LittleFS.open("/blending_duration", "r");
  if (file && file.read(bufBlending, sizeof(bufBlending))) {
      configBlendingDuration = atoi((const char*)bufBlending);
      Serial.print("Blending duration (ms): ");
      Serial.println(configBlendingDuration);
  }

  unsigned char bufDimmingStart[4] = {'\0'};
  file = LittleFS.open("/dimming_start", "r");
  if (file && file.read(bufDimmingStart, sizeof(bufDimmingStart))) {
    configDimmingStart = atoi((const char*)bufDimmingStart);
    Serial.print("Dimming start hour: ");
    Serial.println(configDimmingStart);
  }

  unsigned char bufDimmingEnd[4] = {'\0'};
  file = LittleFS.open("/dimming_end", "r");
  if (file && file.read(bufDimmingEnd, sizeof(bufDimmingEnd))) {
    configDimmingEnd = atoi((const char*)bufDimmingEnd);
    Serial.print("Dimming end hour: ");
    Serial.println(configDimmingEnd);
  }

  unsigned char bufHourFormat[4] = {'\0'};
  file = LittleFS.open("/hour_format", "r");
  if (file && file.read(bufHourFormat, sizeof(bufHourFormat))) {
        configHourFormat = atoi((const char*)bufHourFormat); // 12 or 24
        Serial.print("Hour format: ");
        Serial.println(configHourFormat);
    } else {
        configHourFormat = 12; // default
    }

  return 0;
}

void saveParamsCallback() {
    File file = LittleFS.open("/timezone", "w");
    Serial.println("Saving timezone: " + String(paramTimezone.getValue()));
    file.print(paramTimezone.getValue());
    file.close();

    file = LittleFS.open("/dimming", "w");
    Serial.println("Saving dimming duty cycle: " + String(paramDimmingDutyCycle.getValue()));
    file.print(paramDimmingDutyCycle.getValue()); // save as integer string
    file.close();
    configDimmingDutyCycle = atoi(paramDimmingDutyCycle.getValue()); // update runtime value

    file = LittleFS.open("/modes", "w");
    file.print(paramDisplayMode.getValue());
    file.close();

    file = LittleFS.open("/blending_duration", "w");
    file.print(paramBlendingDuration.getValue());
    file.close();
    configBlendingDuration = atoi(paramBlendingDuration.getValue());

    file = LittleFS.open("/dimming_start", "w");
    file.print(paramDimmingStart.getValue());
    file.close();
    configDimmingStart = atoi(paramDimmingStart.getValue());

    file = LittleFS.open("/dimming_end", "w");
    file.print(paramDimmingEnd.getValue());
    file.close();
    configDimmingEnd = atoi(paramDimmingEnd.getValue());

    file = LittleFS.open("/timeserver", "w");
    Serial.println("Saving timeserver: " + String(paramNetworkTimeServer.getValue()));
    file.print(paramNetworkTimeServer.getValue());
    file.close();

    file = LittleFS.open("/hour_format", "w");
    Serial.println("Saving hour format: " + String(paramHourFormat.getValue()));
    file.print(paramHourFormat.getValue());
    file.close();
    configHourFormat = atoi(paramHourFormat.getValue());

    loadClockConfig();
}



portMUX_TYPE displayMux = portMUX_INITIALIZER_UNLOCKED;
int calibration = 0;
int ps = 0;
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
void loop() {
    wm.process();
    wifiManagerProcessCount++;
    vTaskDelay(pdMS_TO_TICKS(10)); // Keep loop responsive, but display is handled by DisplayTask
}

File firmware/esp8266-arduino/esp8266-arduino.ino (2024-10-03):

/*
https://github.com/laurivosandi/nixiesp12/blob/master/firmware/main.py
https://randomnerdtutorials.com/wifimanager-with-esp8266-autoconnect-custom-parameter-and-manage-your-ssid-and-password/
*/
#include <LittleFS.h>
#include <WiFiManager.h>
#include <ezTime.h>
#include "cities.h"

// #define DEBUG 1
// #define DIMMING_ENABLED 1
// #define TEST_SEQUENCE 1

#define PIN_CLOCK 3
#define PIN_DATA 2
#define PIN_LATCH 0

#define SUNRISE 6
#define SUNSET 22

// ezTime structs
tmElements_t tm;
Timezone local;

int configDimmingDutyCycle = 0;

int current_dimming_duty_cycle;
enum typeOperationMode {
  OPERATION_MODE_NORMAL,
  OPERATION_MODE_DIMMED,
} operationModeCurrent = OPERATION_MODE_NORMAL;

#define DISPLAY_MODE_TIME 1
#define DISPLAY_MODE_DATE 2
#define DISPLAY_MODE_DATETIME 3

int configDisplayModesEnabled = 1;
int displayModeCurrent = 1;

WiFiManager wm;

const char displayModesCombobox[] = R"(
<br/>
<label for="displayModeCombobox">Clock display format</label>
<select name="timeDisplay" id="displayModeCombobox" onchange="document.getElementById('displayMode').value = this.value">
  <option value="1">Time</option>
  <option value="2">Date</option>
  <option value="3">Time and Date</option>
</select>
<script>
  document.getElementById("displayModeCombobox").value = document.getElementById("displayMode").value;
  document.querySelector("[for='displayMode']").hidden = true;
  document.getElementById("displayMode").hidden = true;
</script>)";

#ifdef DIMMING_ENABLED
const char dimmerSliderSnippet[] = R"(
<br/><label for='dimming_duty_cycle_slider'>Night time dimming</label>
<input type="range" min="1" max="3840" value="1000" class="slider" id="dimming_duty_cycle_slider" onchange="document.getElementById('dimming_duty_cycle').value = this.value">
<script>
document.getElementById('dimming_duty_cycle').hidden = true;
</script>
)";
#endif

WiFiManagerParameter paramNetworkTimeServer("networkTimeServer", "Network time server", "ee.pool.ntp.org", 63);
WiFiManagerParameter paramDisplayMode("displayMode", "Will be hidden", "1", 2);
WiFiManagerParameter paramDisplayModeCombobox(displayModesCombobox);
WiFiManagerParameter paramCity(cities);
WiFiManagerParameter paramTimezone("timezone", "Timezone encoding", "EET-2EEST,M3.5.0/3,M10.5.0/4", 30);
//WiFiManagerParameter paramLong("long", "Longitude", "26", 10);
//WiFiManagerParameter paramLat("lat", "Latitude", "59", 10);

#ifdef DIMMING_ENABLED
WiFiManagerParameter paramDimmingDutyCycle("dimming_duty_cycle", "", "1000", 4);
WiFiManagerParameter paramDimmingDutyCycleSlider(dimmerSliderSnippet);

// Dimmer settings
volatile long displayInterruptCount = 0;
#endif

volatile bool blink = true;
int lookup[] = {11, 9, 12, 8, 0, 4, 1, 3, 2, 10};

void ICACHE_RAM_ATTR bitbang_bit(int value){
    if(value & 1){
        digitalWrite(PIN_DATA, HIGH);
    }
    else{
        digitalWrite(PIN_DATA, LOW);
    }
    digitalWrite(PIN_CLOCK, HIGH);
    digitalWrite(PIN_CLOCK, LOW);
}

void ICACHE_RAM_ATTR bitbang_digit(int digit){
    int i = 0;
    if (!blink && timeStatus() != timeSet) {
        for(i=0;i<4;i++){
            bitbang_bit(1);
        }
    } else {
        for(i=0;i<4;i++){
            bitbang_bit(lookup[digit] << i >> 3);
        }
    }
}

void ICACHE_RAM_ATTR renderTest(int j) {
    for(int i=0; i<6; i++){
        bitbang_bit(0);
        bitbang_digit(j);
        bitbang_bit(0);
        bitbang_bit(0);
        bitbang_bit(0);
    }
    digitalWrite(PIN_LATCH, HIGH);
    digitalWrite(PIN_LATCH, LOW);
}

void ICACHE_RAM_ATTR renderTime(){
    int hour = tm.Hour;
    int minute = tm.Minute;
    int second = tm.Second;
    bitbang_bit(0);
    bitbang_digit(hour / 10);
    bitbang_bit(0);
    bitbang_bit(0);
    bitbang_bit(0);

    bitbang_bit(0);
    bitbang_digit(hour % 10);
    bitbang_bit(blink);
    bitbang_bit(blink);
    bitbang_bit(blink);

    bitbang_bit(blink);
    bitbang_digit(minute / 10);
    bitbang_bit(0);
    bitbang_bit(0);
    bitbang_bit(0);

    bitbang_bit(0);
    bitbang_digit(minute % 10);
    bitbang_bit(blink);
    bitbang_bit(blink);
    bitbang_bit(blink);

    bitbang_bit(blink);
    bitbang_digit(second / 10);
    bitbang_bit(0);
    bitbang_bit(0);
    bitbang_bit(0);

    bitbang_bit(0);
    bitbang_digit(second % 10);
    bitbang_bit(0);
    bitbang_bit(0);
    bitbang_bit(0);
}

void ICACHE_RAM_ATTR renderDate(){
    int day = tm.Day;
    int month = tm.Month;
    int year = tm.Year-30;
    bitbang_bit(0);
    bitbang_digit((year) / 10);
    bitbang_bit(0);
    bitbang_bit(0);
    bitbang_bit(0);

    bitbang_bit(0);
    bitbang_digit((year) % 10);
    bitbang_bit(0);
    bitbang_bit(1);
    bitbang_bit(0);

    bitbang_bit(0);
    bitbang_digit(month/ 10);
    bitbang_bit(0);
    bitbang_bit(0);
    bitbang_bit(0);

    bitbang_bit(0);
    bitbang_digit(month % 10);
    bitbang_bit(0);
    bitbang_bit(1);
    bitbang_bit(0);

    bitbang_bit(0);
    bitbang_digit(day / 10);
    bitbang_bit(0);
    bitbang_bit(0);
    bitbang_bit(0);

    bitbang_bit(0);
    bitbang_digit(day % 10);
    bitbang_bit(0);
    bitbang_bit(0);
    bitbang_bit(0);
}

void ICACHE_RAM_ATTR renderDisplay() {
    switch (configDisplayModesEnabled) {
        case 1:
            renderTime();
            break;
        case 2:
            renderDate();
            break;
        case 3:
            if (millis() % 30000 < 15000) {
                renderTime();
            } else {
                renderDate();
            }
            break;
    }
    digitalWrite(PIN_LATCH, HIGH);
    digitalWrite(PIN_LATCH, LOW);
}

void ICACHE_RAM_ATTR clearDisplay() {
  for(int i=0; i<6; i++){
    bitbang_bit(1);
    bitbang_bit(0);
    bitbang_bit(0);
    bitbang_bit(0);
    bitbang_bit(0);
    bitbang_bit(1);
    bitbang_bit(1);
    bitbang_bit(1);
  }

  digitalWrite(PIN_LATCH, HIGH);
  digitalWrite(PIN_LATCH, LOW);
}

int counter = 0;

struct timeval tv;

#ifdef DIMMING_ENABLED
void ICACHE_RAM_ATTR dimmerTimerCallback() {
    noInterrupts();
    displayInterruptCount++;
    gettimeofday(&tv, NULL);
    blink = tv.tv_usec < 500000;
    int j = current_dimming_duty_cycle;
    if (j < configDimmingDutyCycle) {
        j = configDimmingDutyCycle;
    }

  //  if (counter == 0) {
        renderDisplay();
        timer1_write(j+1);
  //      counter = 1;
  //  } else if (counter == 1) {
  //      clearDisplay();
  //      timer1_write(3840-j+1);
  //      counter = 0;
  //  }
    interrupts();
}
#endif
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

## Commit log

2017-06-11 Rotate tubes and other fixes
    [nixiesp.kicad_pcb, nixiesp.sch]
2017-08-08 Hopefully final changes
    [nixiesp.kicad_pcb, nixiesp.sch]
2017-08-08 More assembly tips
2018-11-25 Perfected design
    [nixiesp.kicad_pcb, nixiesp.sch]
2018-12-19 Fixed clock drift and added setup wizard
    [main.py]
2018-12-23 Final fixes
    [frame.scad, nixiesp.kicad_pcb, nixiesp.sch]
2021-07-11 Increase pin socket diameter to 1.6mm
    [nixiesp.kicad_pcb]
2024-07-21 Plastic parts additions and fixes
    [colon-stand.scad, frame.scad]
2024-10-03 Bump PCB thickness
    [frame.scad]
2024-10-03 Add Arduino rewrite of firmware
2025-12-14 Fix zero hour handling for 12-hour mode
    [esp32c3-arduino.ino]
2026-06-17 Bump setup-arduino-cli action version
